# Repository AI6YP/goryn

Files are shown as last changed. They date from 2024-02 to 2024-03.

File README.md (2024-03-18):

# Горынь

* GOWIN FPGA GW2AR-LV18QN88C8/I7 QN88
* 4 x 30pin FPC LVDS capable connectors
* FLASH 64MiB
* 3v3, 1v0 DC-DC converters

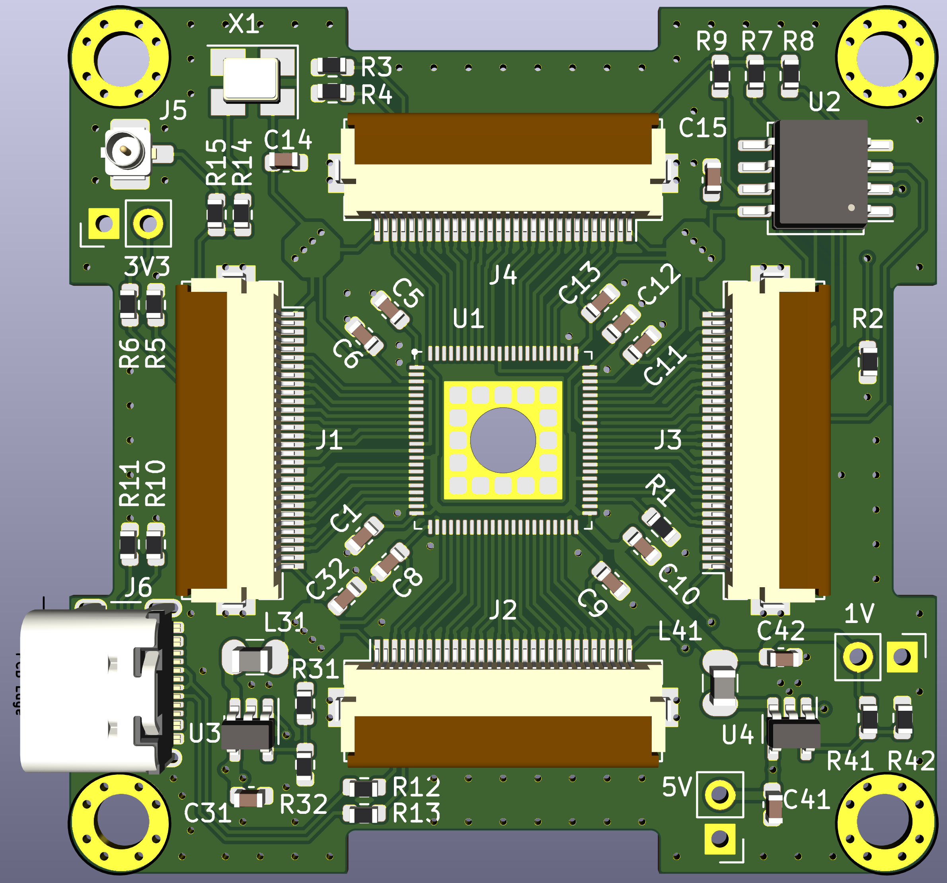
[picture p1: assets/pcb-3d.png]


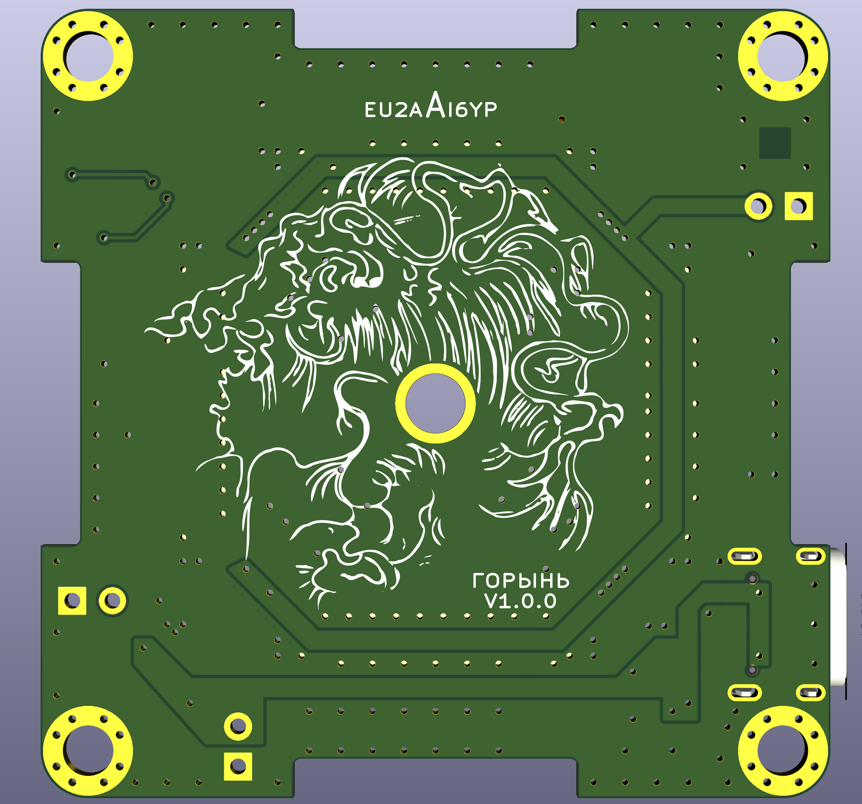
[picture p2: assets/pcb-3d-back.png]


## BOM

https://ai6yp.github.io/goryn/ibom.html

## Goryn on the map

Locator: KO31ku

https://www.google.com/maps/@51.8671689,26.8422638,6338m/data=!3m1!1e3

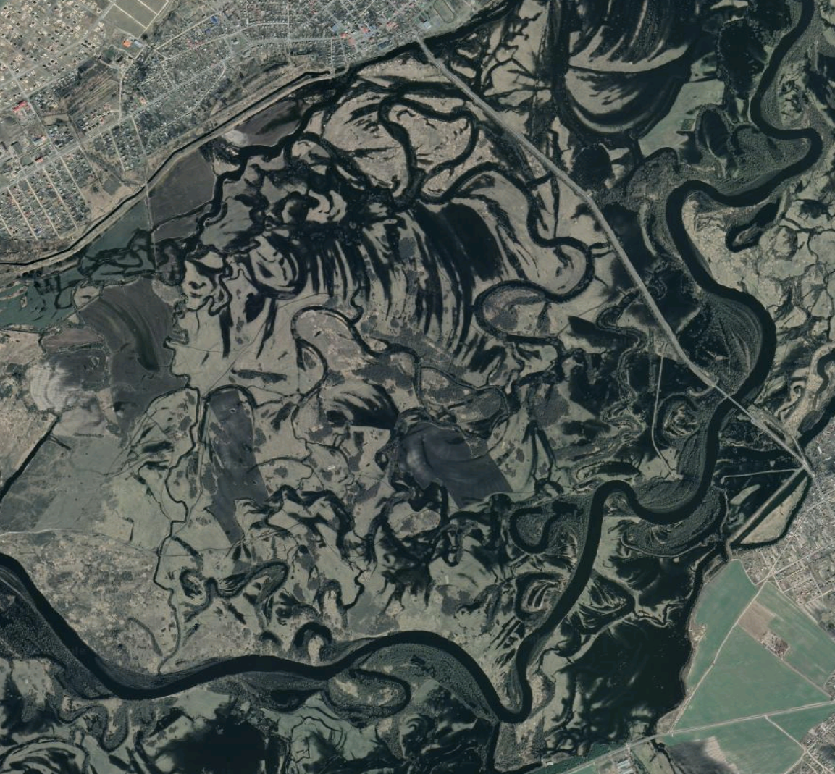
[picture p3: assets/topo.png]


## License

Hardware is released under the <a href="https://creativecommons.org/licenses/by/4.0/"> CC BY 4.0 </a> [[LICENSE](LICENSE)].

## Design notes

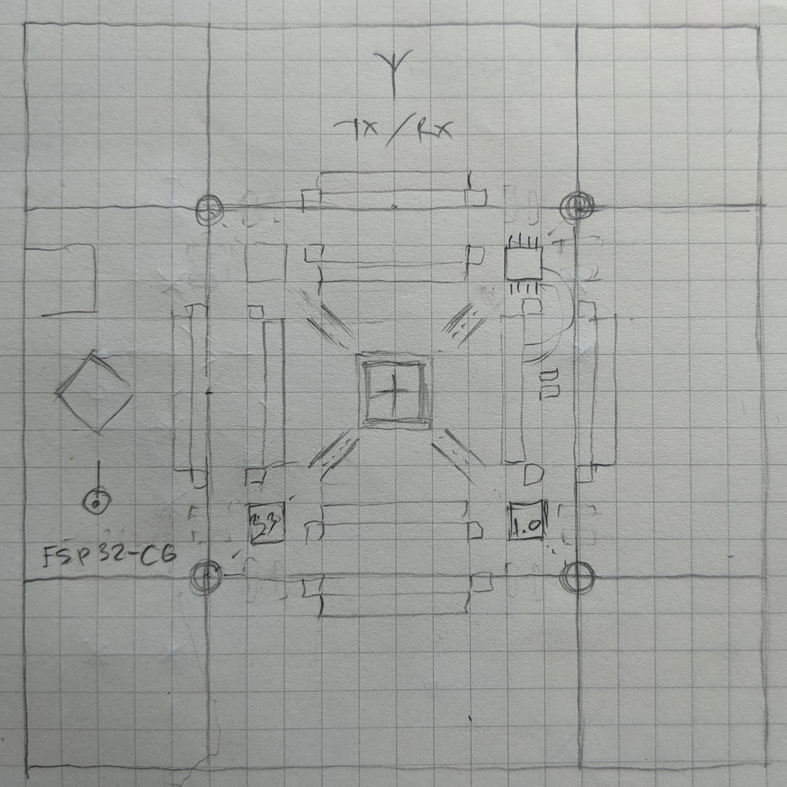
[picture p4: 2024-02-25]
assets/sketch.jpg

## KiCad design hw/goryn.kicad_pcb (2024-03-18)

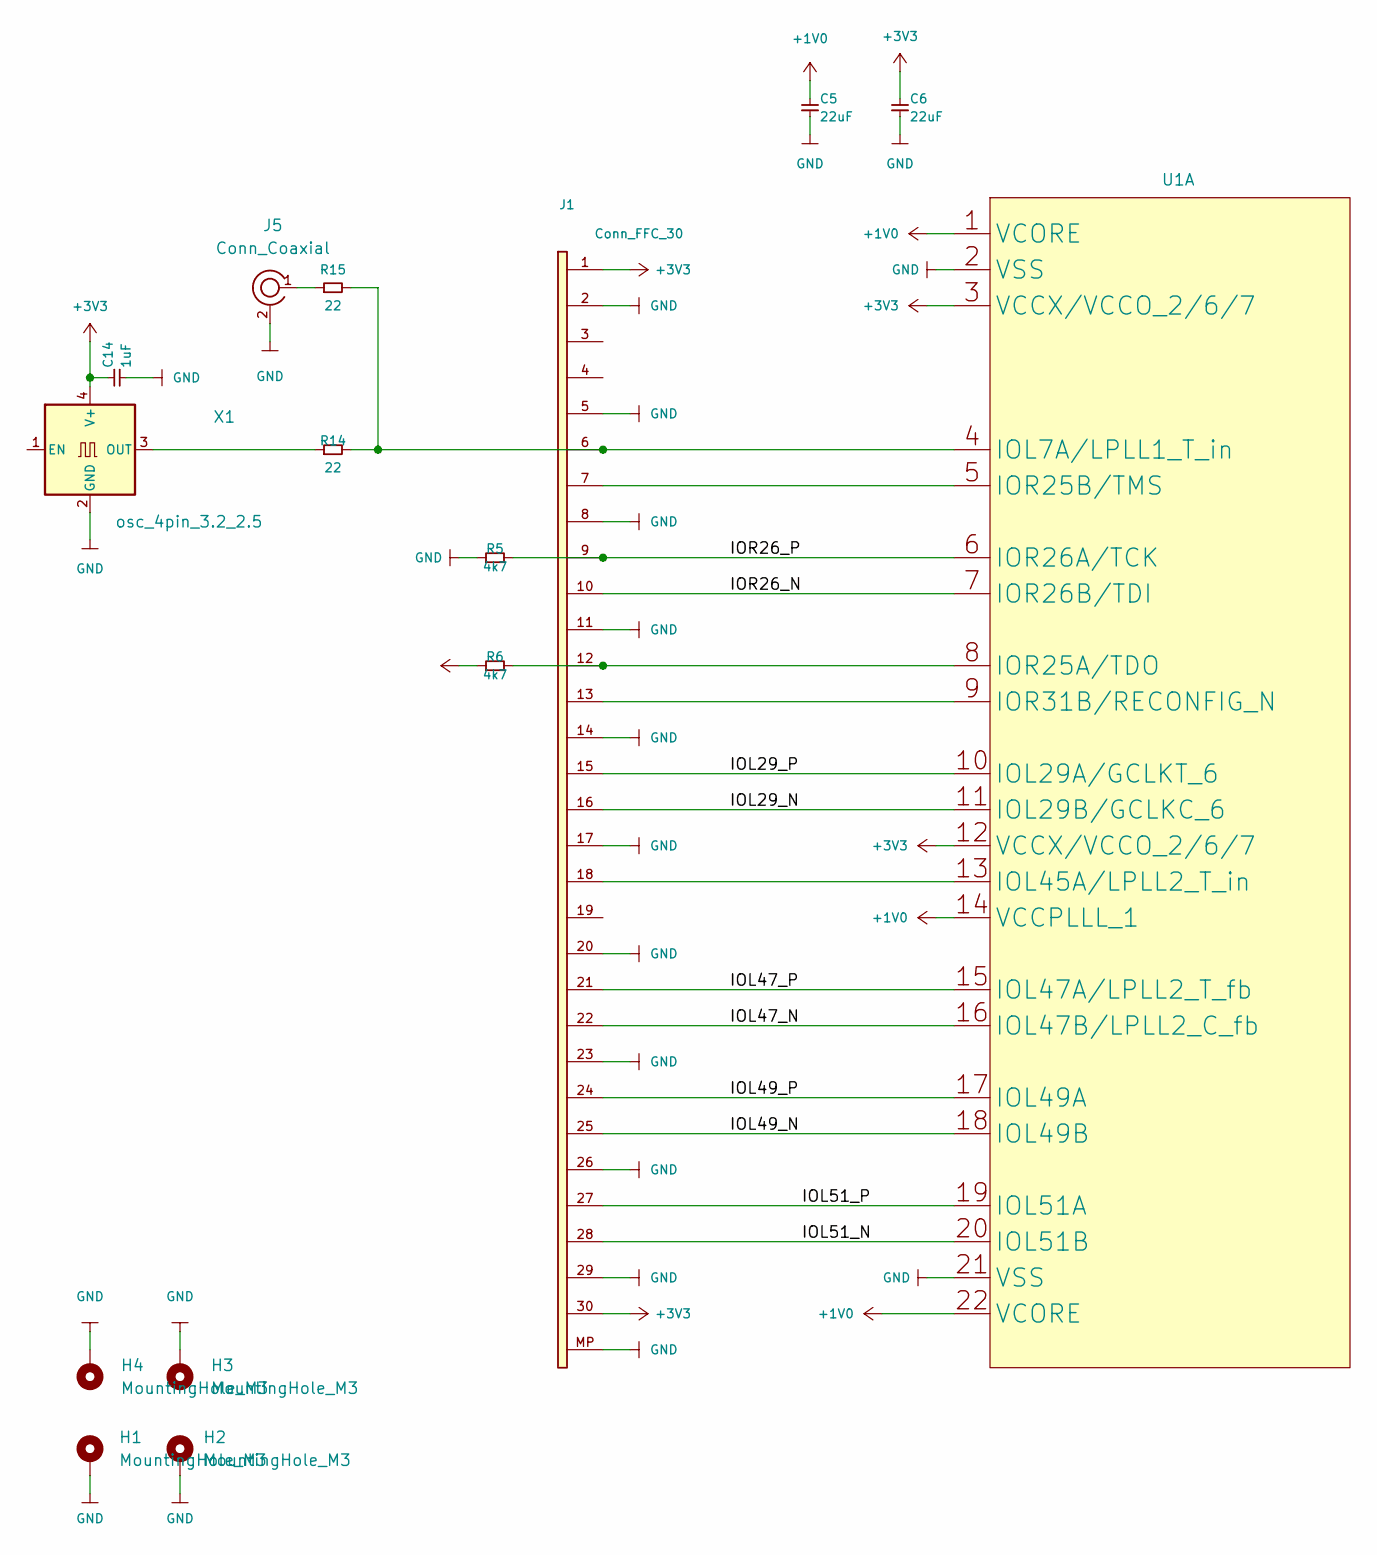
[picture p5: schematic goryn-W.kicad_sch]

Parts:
C5, C6: 22uF; C_0603_1608Metric
C14: 1uF; C_0603_1608Metric
H1, H2, H3, H4: MountingHole_M3; MountingHole_3.2mm_M3_Pad_Via
J1: Conn_FFC_30; Hirose_FH12-30S-0.5SH_1x30-1MP_P0.50mm_Horizontal
J5: Conn_Coaxial; U.FL_Hirose_U.FL-R-SMT-1_Vertical
R5, R6: 4k7; R_0603_1608Metric
R14, R15: 22; R_0603_1608Metric
U1: GIWIN-QFN-88-10x10mm-P0.4mm-EP6.74x6.74mm
X1: osc_4pin_3.2_2.5; Crystal_SMD_EuroQuartz_MT-4Pin_3.2x2.5mm_HandSoldering

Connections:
+1V0: C5.1, U1.1 (VCORE), U1.14 (VCCPLLL_1), U1.22 (VCORE); also elsewhere on the board
+3V3: C6.1, C14.1, J1.1, J1.30, R6.1, U1.3 (VCCX/VCCO_2/6/7), U1.12 (VCCX/VCCO_2/6/7), X1.4 (V+); also elsewhere on the board
/West/IOL29_N: J1.16, U1.11 (IOL29B/GCLKC_6)
/West/IOL29_P: J1.15, U1.10 (IOL29A/GCLKT_6)
/West/IOL47_N: J1.22, U1.16 (IOL47B/LPLL2_C_fb)
/West/IOL47_P: J1.21, U1.15 (IOL47A/LPLL2_T_fb)
/West/IOL49_N: J1.25, U1.18 (IOL49B)
/West/IOL49_P: J1.24, U1.17 (IOL49A)
/West/IOL51_N: J1.28, U1.20 (IOL51B)
/West/IOL51_P: J1.27, U1.19 (IOL51A)
/West/IOR26_N: J1.10, U1.7 (IOR26B/TDI)
/West/IOR26_P: J1.9, R5.2, U1.6 (IOR26A/TCK)
GND: C5.2, C6.2, C14.2, H1.1, H2.1, H3.1, H4.1, J1.2, J1.5, J1.8, J1.11, J1.14, J1.17, J1.20, J1.23, J1.26, J1.29, J1.MP, J5.2 (Ext), R5.1, U1.2 (VSS), U1.21 (VSS), X1.2 (GND); also elsewhere on the board
unnamed: J1.6, R14.2, R15.2, U1.4 (IOL7A/LPLL1_T_in)
unnamed: J1.7, U1.5 (IOR25B/TMS)
unnamed: J1.12, R6.2, U1.8 (IOR25A/TDO)
unnamed: J1.13, U1.9 (IOR31B/RECONFIG_N)
unnamed: J1.18, U1.13 (IOL45A/LPLL2_T_in)
unnamed: J5.1 (In), R15.1
unnamed: R14.1, X1.3 (OUT)

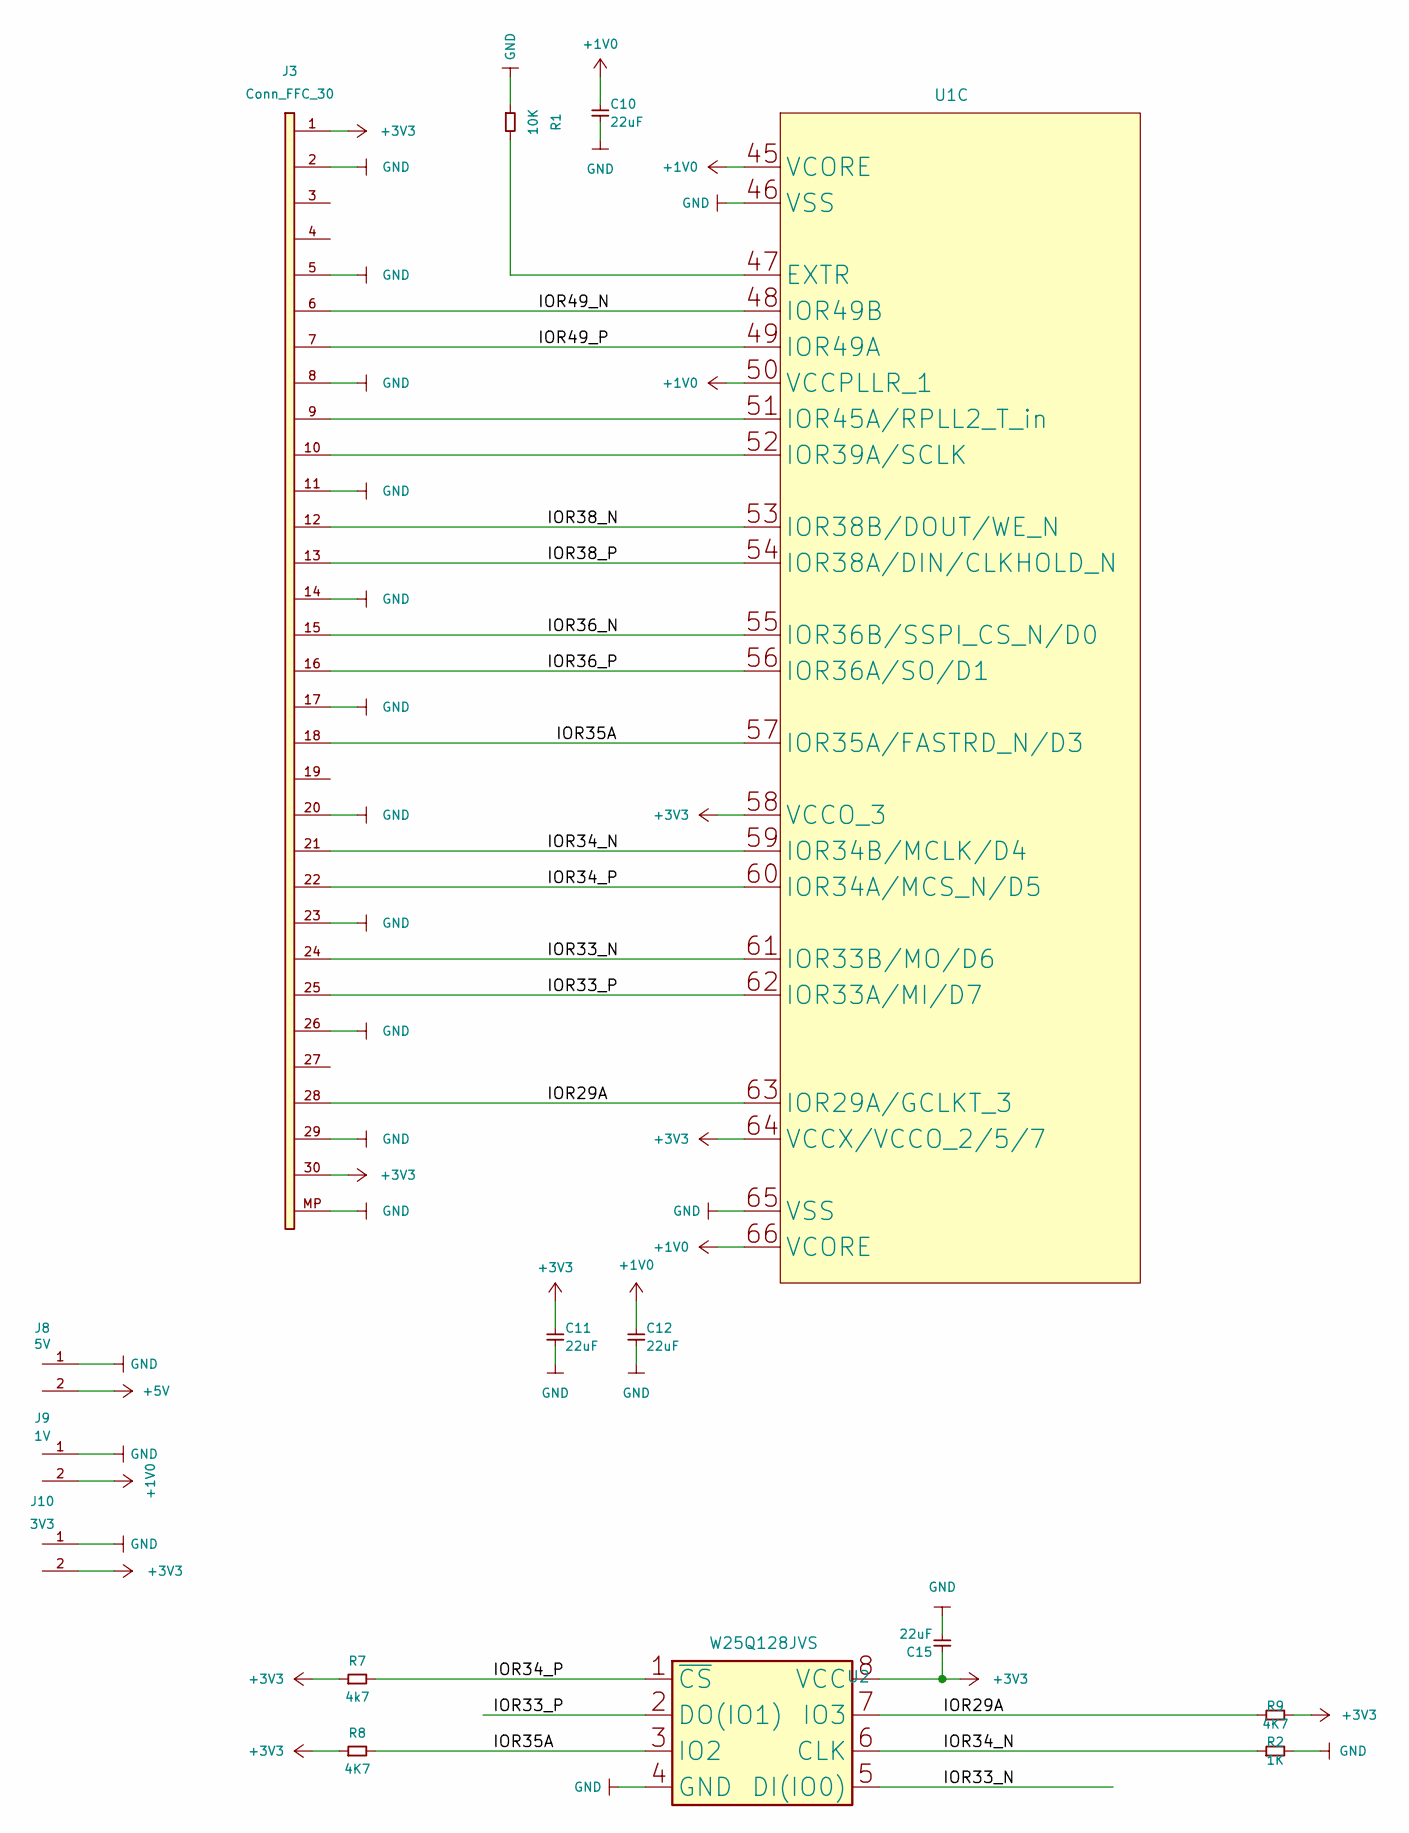
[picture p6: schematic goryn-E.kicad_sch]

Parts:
C10, C11, C12, C15: 22uF; C_0603_1608Metric
J3: Conn_FFC_30; Hirose_FH12-30S-0.5SH_1x30-1MP_P0.50mm_Horizontal
J8: 5V; PinHeader_1x02_P2.54mm_Vertical
J9: 1V; PinHeader_1x02_P2.54mm_Vertical
J10: 3V3; PinHeader_1x02_P2.54mm_Vertical
R1: 10K; R_0603_1608Metric
R2: 1K; R_0603_1608Metric
R7: 4k7; R_0603_1608Metric
R8, R9: 4K7; R_0603_1608Metric
U1: GIWIN-QFN-88-10x10mm-P0.4mm-EP6.74x6.74mm
U2: W25Q128JVS; SO-8_5.3x6.2mm_P1.27mm

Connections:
+1V0: C10.1, C12.1, J9.2, U1.45 (VCORE), U1.50 (VCCPLLR_1), U1.66 (VCORE); also elsewhere on the board
+3V3: C11.1, C15.1, J3.1, J3.30, J10.2, R7.1, R8.1, R9.2, U1.58 (VCCO_3), U1.64 (VCCX/VCCO_2/5/7), U2.8 (VCC); also elsewhere on the board
+5V: J8.2; also elsewhere on the board
/East/IOR29A: J3.28, R9.1, U1.63 (IOR29A/GCLKT_3), U2.7 (IO3)
/East/IOR33_N: J3.24, U1.61 (IOR33B/MO/D6), U2.5 (DI(IO0))
/East/IOR33_P: J3.25, U1.62 (IOR33A/MI/D7), U2.2 (DO(IO1))
/East/IOR34_N: J3.21, R2.1, U1.59 (IOR34B/MCLK/D4), U2.6 (CLK)
/East/IOR34_P: J3.22, R7.2, U1.60 (IOR34A/MCS_N/D5), U2.1 (~CS)
/East/IOR35A: J3.18, R8.2, U1.57 (IOR35A/FASTRD_N/D3), U2.3 (IO2)
/East/IOR36_N: J3.15, U1.55 (IOR36B/SSPI_CS_N/D0)
/East/IOR36_P: J3.16, U1.56 (IOR36A/SO/D1)
/East/IOR38_N: J3.12, U1.53 (IOR38B/DOUT/WE_N)
/East/IOR38_P: J3.13, U1.54 (IOR38A/DIN/CLKHOLD_N)
/East/IOR49_N: J3.6, U1.48 (IOR49B)
/East/IOR49_P: J3.7, U1.49 (IOR49A)
GND: C10.2, C11.2, C12.2, C15.2, J3.2, J3.5, J3.8, J3.11, J3.14, J3.17, J3.20, J3.23, J3.26, J3.29, J3.MP, J8.1, J9.1, J10.1, R1.1, R2.2, U1.46 (VSS), U1.65 (VSS), U2.4 (GND); also elsewhere on the board
unnamed: J3.9, U1.51 (IOR45A/RPLL2_T_in)
unnamed: J3.10, U1.52 (IOR39A/SCLK)
unnamed: R1.2, U1.47 (EXTR)

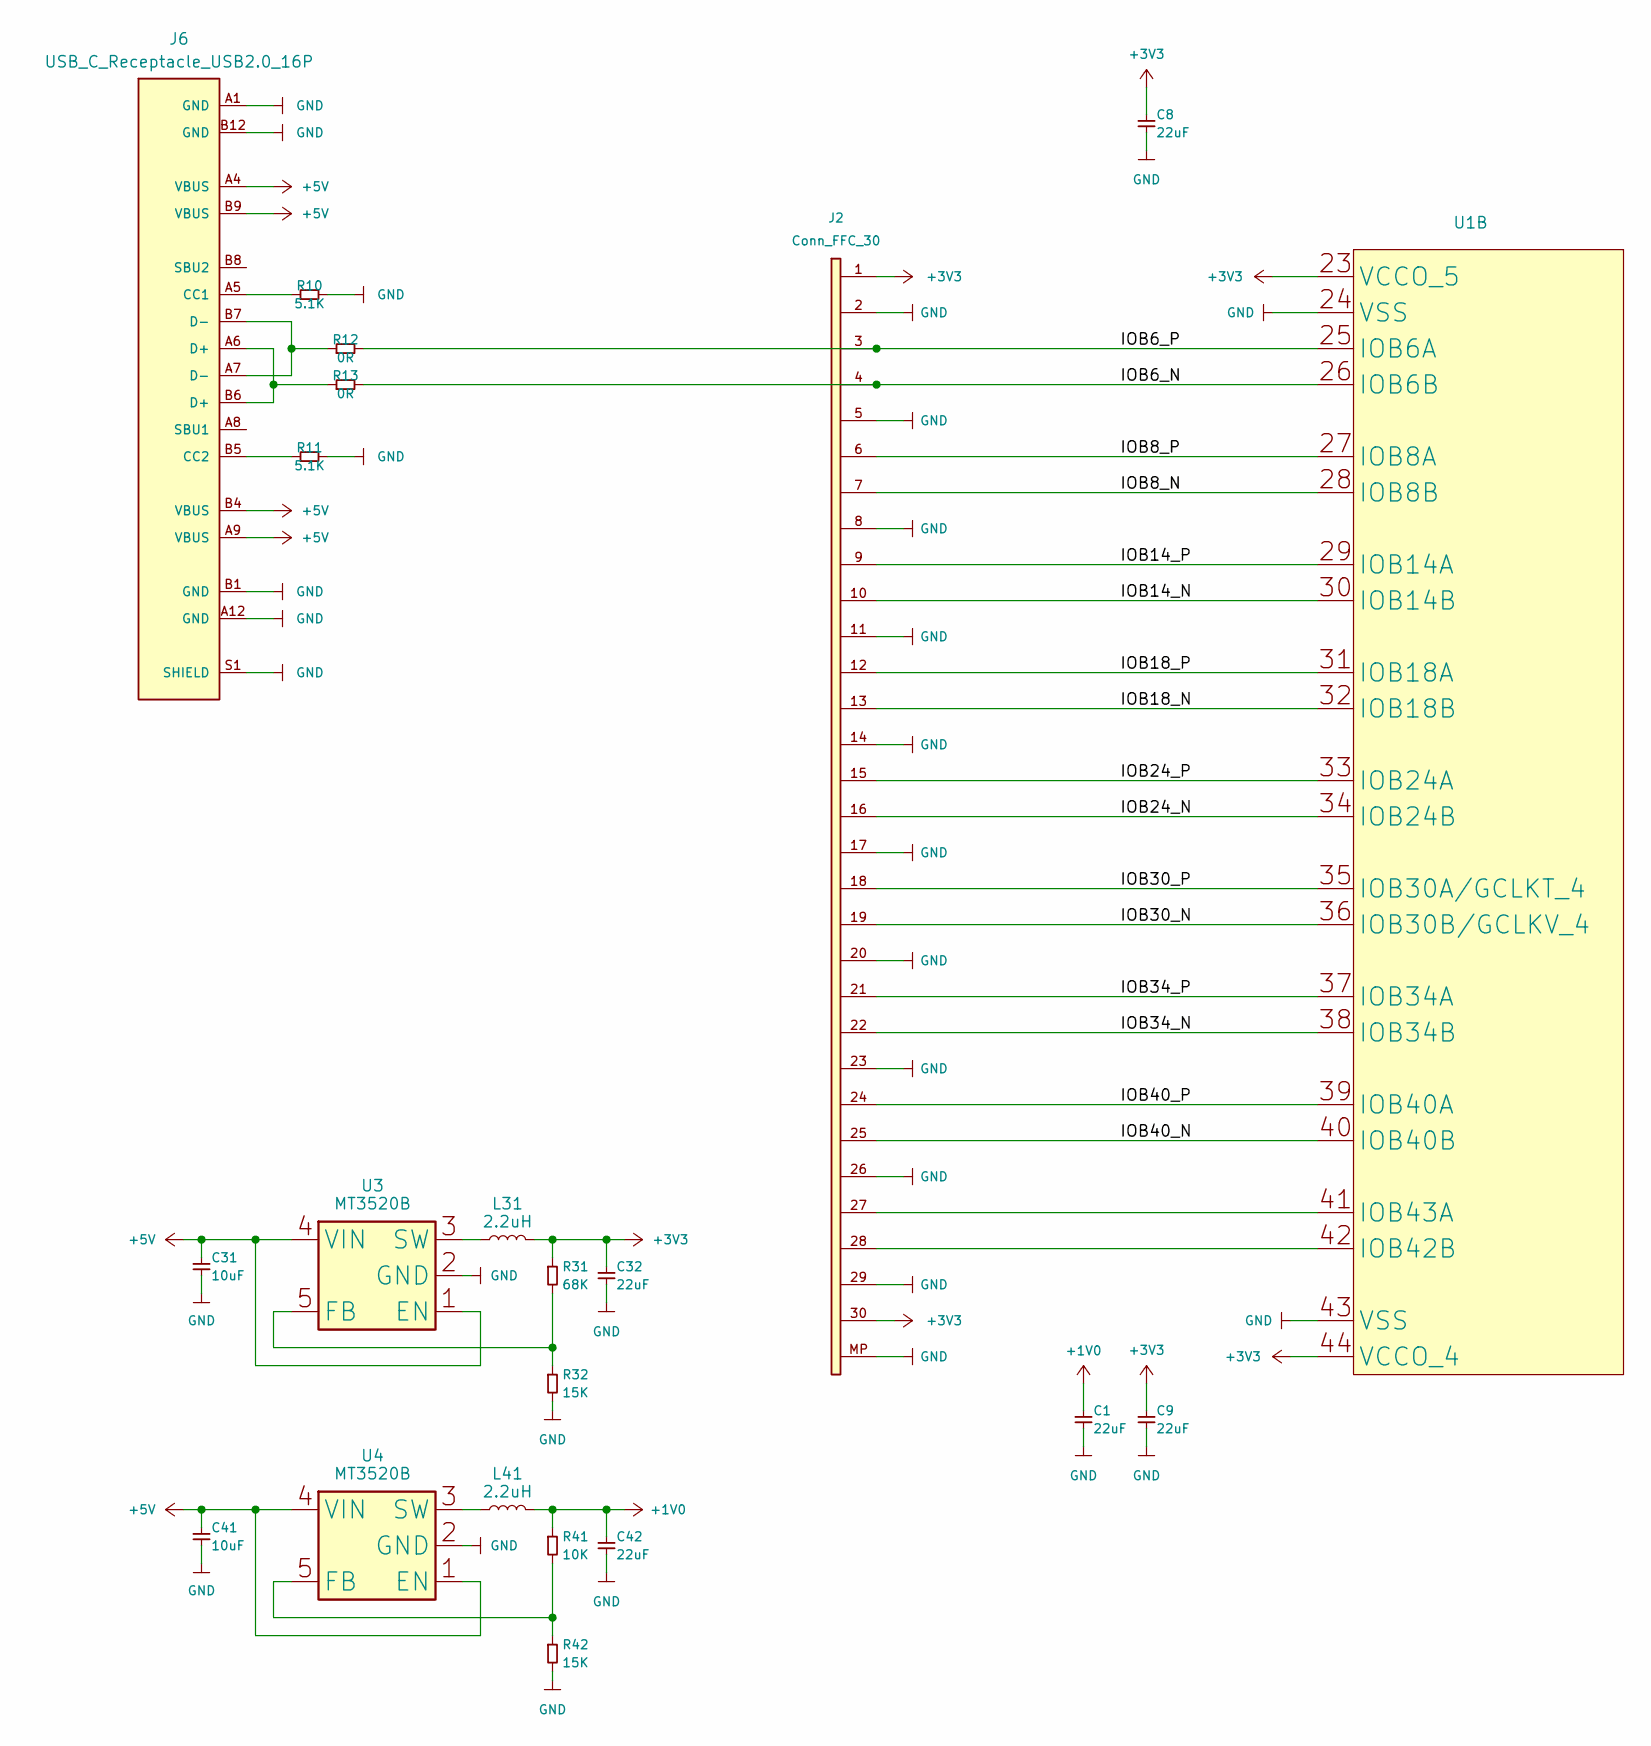
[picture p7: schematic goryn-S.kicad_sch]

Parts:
C1, C8, C9, C32, C42: 22uF; C_0603_1608Metric
C31, C41: 10uF; C_0603_1608Metric
J2: Conn_FFC_30; Hirose_FH12-30S-0.5SH_1x30-1MP_P0.50mm_Horizontal
J6: USB_C_Receptacle_USB2.0_16P; USB_C_Receptacle_GCT_USB4105-xx-A_16P_TopMnt_Horizontal
L31, L41: 2.2uH; L_0805_2012Metric_Pad1.05x1.20mm_HandSolder
R10, R11: 5.1K; R_0603_1608Metric
R12, R13: 0R; R_0603_1608Metric
R31: 68K; R_0603_1608Metric
R32, R42: 15K; R_0603_1608Metric
R41: 10K; R_0603_1608Metric
U1: GIWIN-QFN-88-10x10mm-P0.4mm-EP6.74x6.74mm
U3, U4: MT3520B; SOT-23-5

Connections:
+1V0: C1.1, C42.1, L41.2, R41.1; also elsewhere on the board
+3V3: C8.1, C9.1, C32.1, J2.1, J2.30, L31.2, R31.1, U1.23 (VCCO_5), U1.44 (VCCO_4); also elsewhere on the board
+5V: C31.1, C41.1, J6.A4 (VBUS), J6.A9 (VBUS), J6.B4 (VBUS), J6.B9 (VBUS), U3.1 (EN), U3.4 (VIN), U4.1 (EN), U4.4 (VIN); also elsewhere on the board
/South/IOB6_N: J2.4, R13.2, U1.26 (IOB6B)
/South/IOB6_P: J2.3, R12.2, U1.25 (IOB6A)
/South/IOB8_N: J2.7, U1.28 (IOB8B)
/South/IOB8_P: J2.6, U1.27 (IOB8A)
/South/IOB14_N: J2.10, U1.30 (IOB14B)
/South/IOB14_P: J2.9, U1.29 (IOB14A)
/South/IOB18_N: J2.13, U1.32 (IOB18B)
/South/IOB18_P: J2.12, U1.31 (IOB18A)
/South/IOB24_N: J2.16, U1.34 (IOB24B)
/South/IOB24_P: J2.15, U1.33 (IOB24A)
/South/IOB30_N: J2.19, U1.36 (IOB30B/GCLKV_4)
/South/IOB30_P: J2.18, U1.35 (IOB30A/GCLKT_4)
/South/IOB34_N: J2.22, U1.38 (IOB34B)
/South/IOB34_P: J2.21, U1.37 (IOB34A)
/South/IOB40_N: J2.25, U1.40 (IOB40B)
/South/IOB40_P: J2.24, U1.39 (IOB40A)
GND: C1.2, C8.2, C9.2, C31.2, C32.2, C41.2, C42.2, J2.2, J2.5, J2.8, J2.11, J2.14, J2.17, J2.20, J2.23, J2.26, J2.29, J2.MP, J6.A1 (GND), J6.A12 (GND), J6.B1 (GND), J6.B12 (GND), J6.S1 (SHIELD), R10.2, R11.2, R32.2, R42.2, U1.24 (VSS), U1.43 (VSS), U3.2 (GND), U4.2 (GND); also elsewhere on the board
unnamed: J2.27, U1.41 (IOB43A)
unnamed: J2.28, U1.42 (IOB42B)
unnamed: J6.A5 (CC1), R10.1
unnamed: J6.B5 (CC2), R11.1
unnamed: J6.A6 (D+), J6.B6 (D+), R13.1
unnamed: J6.A7 (D-), J6.B7 (D-), R12.1
unnamed: R31.2, R32.1, U3.5 (FB)
unnamed: L31.1, U3.3 (SW)
unnamed: R41.2, R42.1, U4.5 (FB)
unnamed: L41.1, U4.3 (SW)

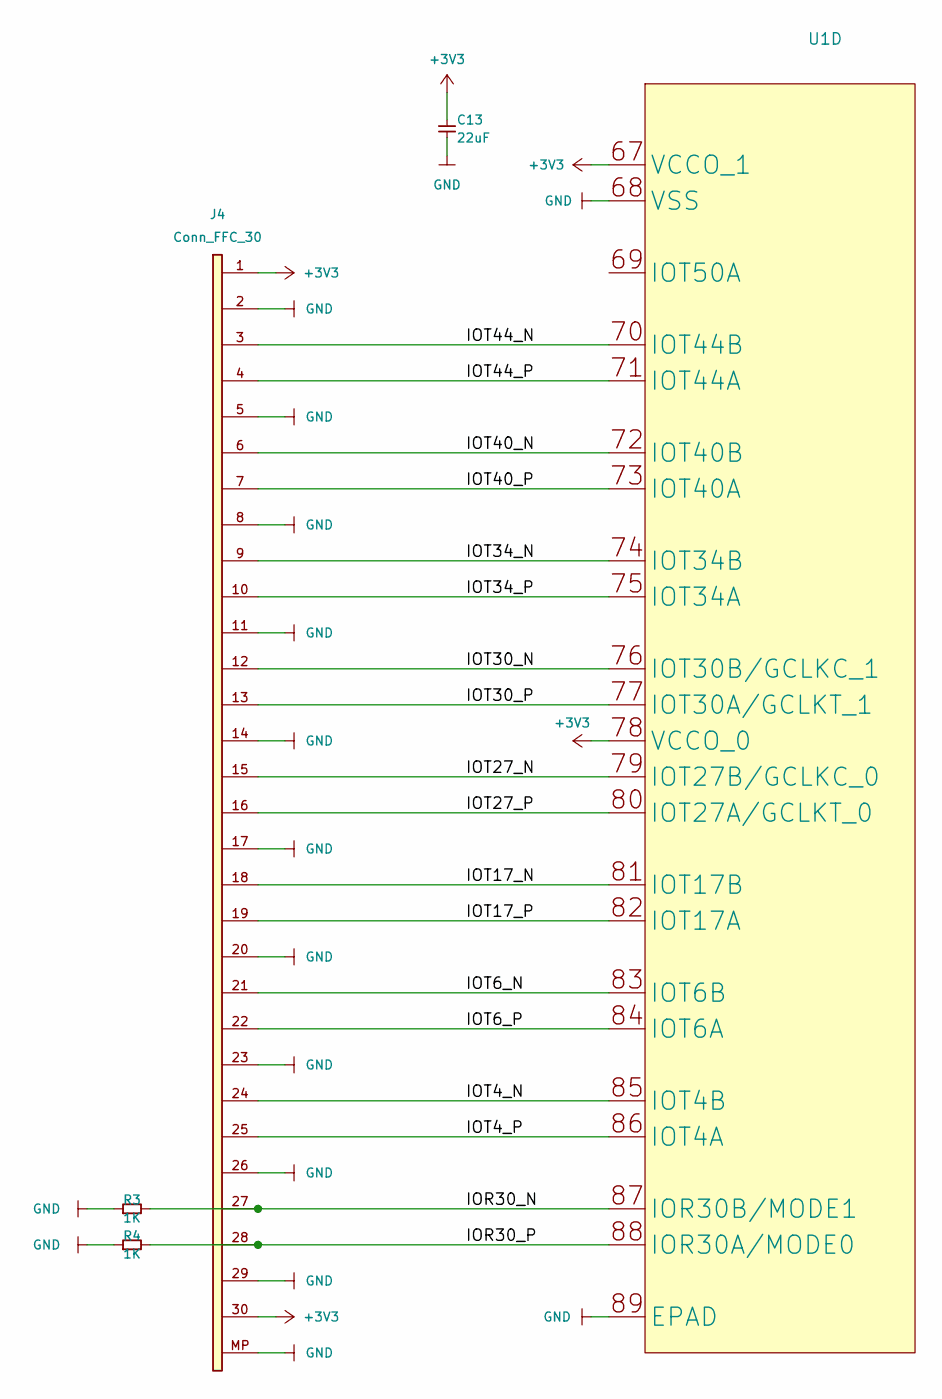
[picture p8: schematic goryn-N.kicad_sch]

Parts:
C13: 22uF; C_0603_1608Metric
J4: Conn_FFC_30; Hirose_FH12-30S-0.5SH_1x30-1MP_P0.50mm_Horizontal
R3, R4: 1K; R_0603_1608Metric
U1: GIWIN-QFN-88-10x10mm-P0.4mm-EP6.74x6.74mm

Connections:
+3V3: C13.1, J4.1, J4.30, U1.67 (VCCO_1), U1.78 (VCCO_0); also elsewhere on the board
/North/IOR30_N: J4.27, R3.2, U1.87 (IOR30B/MODE1)
/North/IOR30_P: J4.28, R4.2, U1.88 (IOR30A/MODE0)
/North/IOT4_N: J4.24, U1.85 (IOT4B)
/North/IOT4_P: J4.25, U1.86 (IOT4A)
/North/IOT6_N: J4.21, U1.83 (IOT6B)
/North/IOT6_P: J4.22, U1.84 (IOT6A)
/North/IOT17_N: J4.18, U1.81 (IOT17B)
/North/IOT17_P: J4.19, U1.82 (IOT17A)
/North/IOT27_N: J4.15, U1.79 (IOT27B/GCLKC_0)
/North/IOT27_P: J4.16, U1.80 (IOT27A/GCLKT_0)
/North/IOT30_N: J4.12, U1.76 (IOT30B/GCLKC_1)
/North/IOT30_P: J4.13, U1.77 (IOT30A/GCLKT_1)
/North/IOT34_N: J4.9, U1.74 (IOT34B)
/North/IOT34_P: J4.10, U1.75 (IOT34A)
/North/IOT40_N: J4.6, U1.72 (IOT40B)
/North/IOT40_P: J4.7, U1.73 (IOT40A)
/North/IOT44_N: J4.3, U1.70 (IOT44B)
/North/IOT44_P: J4.4, U1.71 (IOT44A)
GND: C13.2, J4.2, J4.5, J4.8, J4.11, J4.14, J4.17, J4.20, J4.23, J4.26, J4.29, J4.MP, R3.1, R4.1, U1.68 (VSS), U1.89 (EPAD); also elsewhere on the board

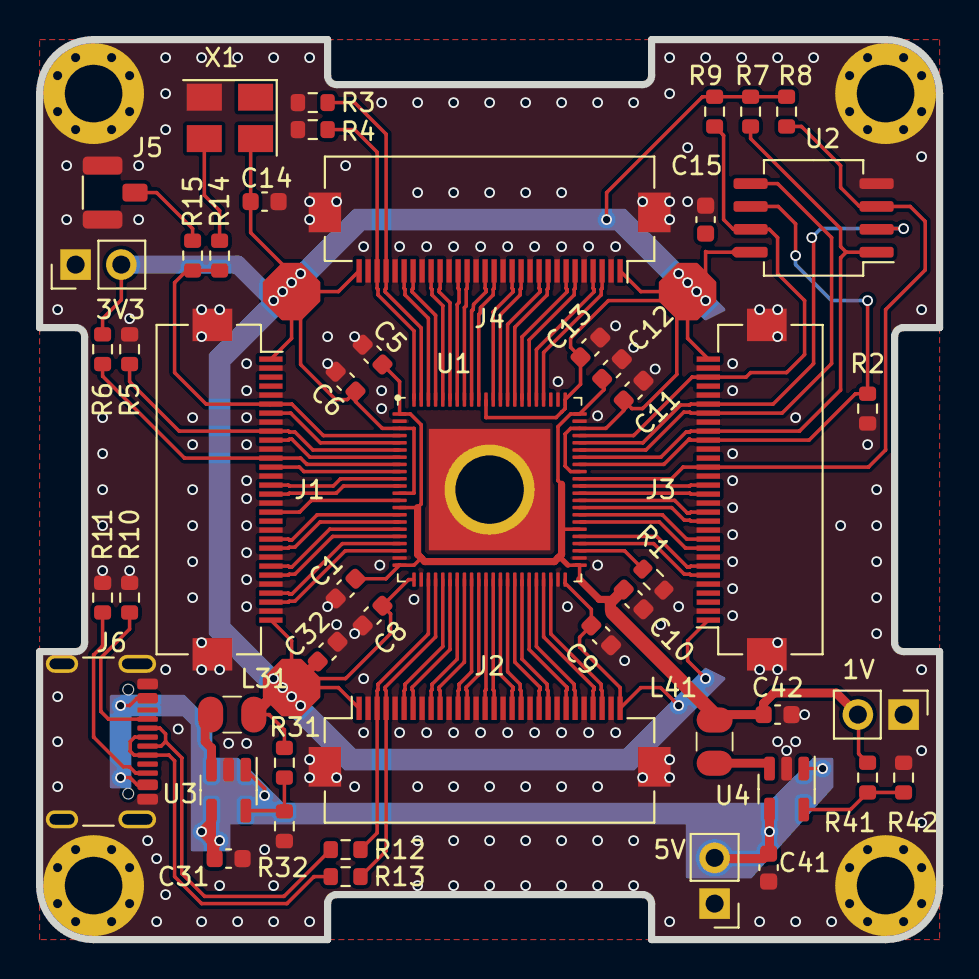
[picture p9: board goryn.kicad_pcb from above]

Board: 2 copper layers, 50.0 x 50.0 mm, 54 parts (0 on the bottom side), 80 nets.

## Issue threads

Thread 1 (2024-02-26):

tributary modules

drom, 2024-02-26:
* ESP32-C6 WIFI / BT
* FTDI FT232H
* PMOD

edmundhumenberger, 2024-02-28:
MIPI-DSI display https://arace.tech/products/display-8-hd

edmundhumenberger, 2024-02-28:
Cruvi high speed base connector , This would allow to use the cruvi adapter boards which are available.
Like EMMC, ethernet, HDMI out, RPI 2-lane cam in, PS.RAM

https://shop.trenz-electronic.de/de/Produkte/Trenz-Electronic/CRUVI/

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

edmundhumenberger, 2024-02-28:
DDR3 memory module. This is important as you want to have large distributed memory accessible from multiple path.
The Gowin FPGA package does have fast SRAM on board

edmundhumenberger, 2024-02-28:
m.2 for NVMe mass storage  module (We do net yet have a PCIe Gen 2 root complex for FPGA, so in the beginning it might be better to do a SATA SSD module)

edmundhumenberger, 2024-02-28:
Syzygy carrier connector to have access to the SDR modules
https://syzygyfpga.io/peripherals/

edmundhumenberger, 2024-02-28:
Multi Voltage SDIO board to make use of full speed of advanced SD cards as removeable mass storage

https://x.com/zipcpu/status/1762850897384595923?s=20

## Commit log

2024-02-24 initial kicad fiels
    [goryn-E.kicad_sch, goryn-N.kicad_sch, goryn-S.kicad_sch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]
2024-02-24 added DC-DC
    [goryn-E.kicad_sch, goryn-N.kicad_sch, goryn-S.kicad_sch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]
2024-02-25 FFC34 -> FFC30
    [goryn-E.kicad_sch, goryn-N.kicad_sch, goryn-S.kicad_sch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]
2024-02-29 connectors spreadsheet
2024-02-29 happy kicad 8
    [goryn-E.kicad_sch, goryn-N.kicad_sch, goryn-S.kicad_sch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]
2024-03-11 finished routing
    [goryn-E.kicad_sch, goryn-N.kicad_sch, goryn-S.kicad_sch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]
2024-03-12 added interactive BOM
2024-03-12 added link to BOM
2024-03-18 updated BOM
